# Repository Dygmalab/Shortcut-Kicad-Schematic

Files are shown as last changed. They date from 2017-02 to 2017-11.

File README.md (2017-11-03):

Shortcut v4 schematic and board layout. This is the version that
[Dygma](http://www.dygma.com) used for conducting closed beta testing of the
shortcut gaming keyboard.

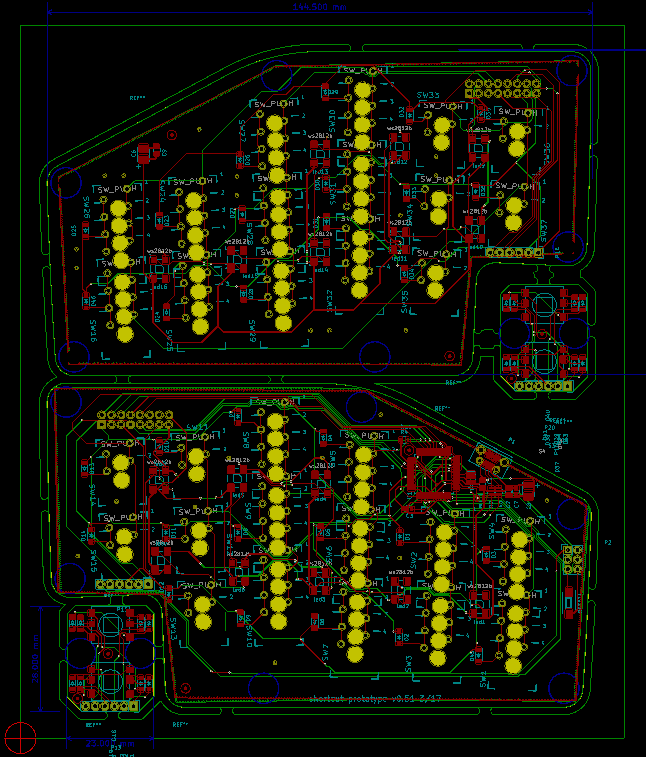
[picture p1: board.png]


[Schematic PDF](schematic.pdf)

Copyright Dygma 2017.

The firmware for the keyboard is part of the [Kaleidoscope
project](https://github.com/keyboardio/Kaleidoscope). The
specific implementation is defined in the [Shortcut Hardware
Plugin](https://github.com/Dygmalab/Kaleidoscope-Hardware-Shortcut).

This documentation describes Open Hardware and is licensed under the
[CERN OHL v. 1.2.](cern_ohl_v_1_2.txt)

You may redistribute and modify this documentation under the terms of the
CERN OHL v.1.2. (http://ohwr.org/cernohl). This documentation is distributed
WITHOUT ANY EXPRESS OR IMPLIED WARRANTY, INCLUDING OF
MERCHANTABILITY, SATISFACTORY QUALITY AND FITNESS FOR A
PARTICULAR PURPOSE. Please see the CERN OHL v.1.2 for applicable
conditions

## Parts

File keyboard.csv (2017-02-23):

Item | Qty | Reference(s) | Value | LibPart | Footprint | Datasheet | farnell #
1 | 2 | C1, C3 | 1u | device:C | Capacitors_SMD:C_0805 |  | 1759422
2 | 3 | C2, C7, C9 | 0.1u | device:C | Capacitors_SMD:C_0805 |  | 1759167
3 | 2 | C6, C8 | 2.2u | device:CP | Capacitors_Tantalum_SMD:TantalC_SizeB_EIA-3528_Reflow |  | 1759424
4 | 46 | D1, D10, D11, D12, D13, D14, D15, D16, D17, D18, D19, D2, D20, D21, D22, D23, D24, D25, D26, D27, D28, D29, D3, D30, D31, D32, D33, D34, D35, D36, D37, D38, D39, D4, D40, D41, D42, D43, D44, D45, D46, D5, D6, D7, D8, D9 | D | device:D | Diodes_SMD:SOD-123 |  | 2454043
5 | 1 | P1 | USB_OTG | conn:USB_OTG |  |  | 2293836
6 | 14 | P10, P11, P12, P13, P14, P17, P20, P3, P4, P5, P6, P7, P8, P9 | CONN_01X01 | conn:CONN_01X01 | Mounting_Holes:MountingHole_4mm
7 | 4 | P15, P16, P18, P19 | CONN_01X06 | conn:CONN_01X06
8 | 1 | P2 | CONN_02X03 | conn:CONN_02X03 | Pin_Headers:Pin_Header_Straight_2x03
9 | 1 | R1 | 10k | device:R | Resistors_SMD:R_0805 |  | 2447553
10 | 2 | R2, R3 | 22r | device:R | Resistors_SMD:R_0805 |  | 9332847
11 | 1 | RESET1 | SW_PUSH | device:SW_PUSH | matt:SW_SPST_FSMSM |  | 9471898
12 | 4 | S1, S2, S3, S4 | alps_4way | alps_4way:alps_4way | fp:alps 4way smt |  | 1435774
13 | 20 | SW1, SW10, SW16, SW2, SW24, SW25, SW26, SW27, SW28, SW29, SW3, SW30, SW31, SW32, SW4, SW5, SW6, SW7, SW8, SW9 | SW_PUSH | device:SW_PUSH | fp:CHERRY_MXx4
14 | 10 | SW11, SW12, SW13, SW14, SW15, SW33, SW34, SW35, SW36, SW37 | SW_PUSH | device:SW_PUSH | fp:CHERRY_MXx2
15 | 1 | U1 | ATmega32U4 | atmel:ATmega32U4 | Housings_QFP:LQFP-44_10x10mm_Pitch0.8mm |  | 1748525
16 | 1 | X1 | CRYSTAL_SMD | device:CRYSTAL_SMD | fp:cstce-v | CSTCE16M0V53 | 2443265
17 | 2 | conn1, conn2 | CONN_02X08 | conn:CONN_02X08 | Socket_Strips:Socket_Strip_Angled_2x08 |  | 1642024
18 | 16 | led1, led10, led11, led12, led13, led14, led15, led16, led2, led3, led4, led5, led6, led7, led8, led9 | ws2812b | ws2812b:ws2812b | WS2812B:WS2812B

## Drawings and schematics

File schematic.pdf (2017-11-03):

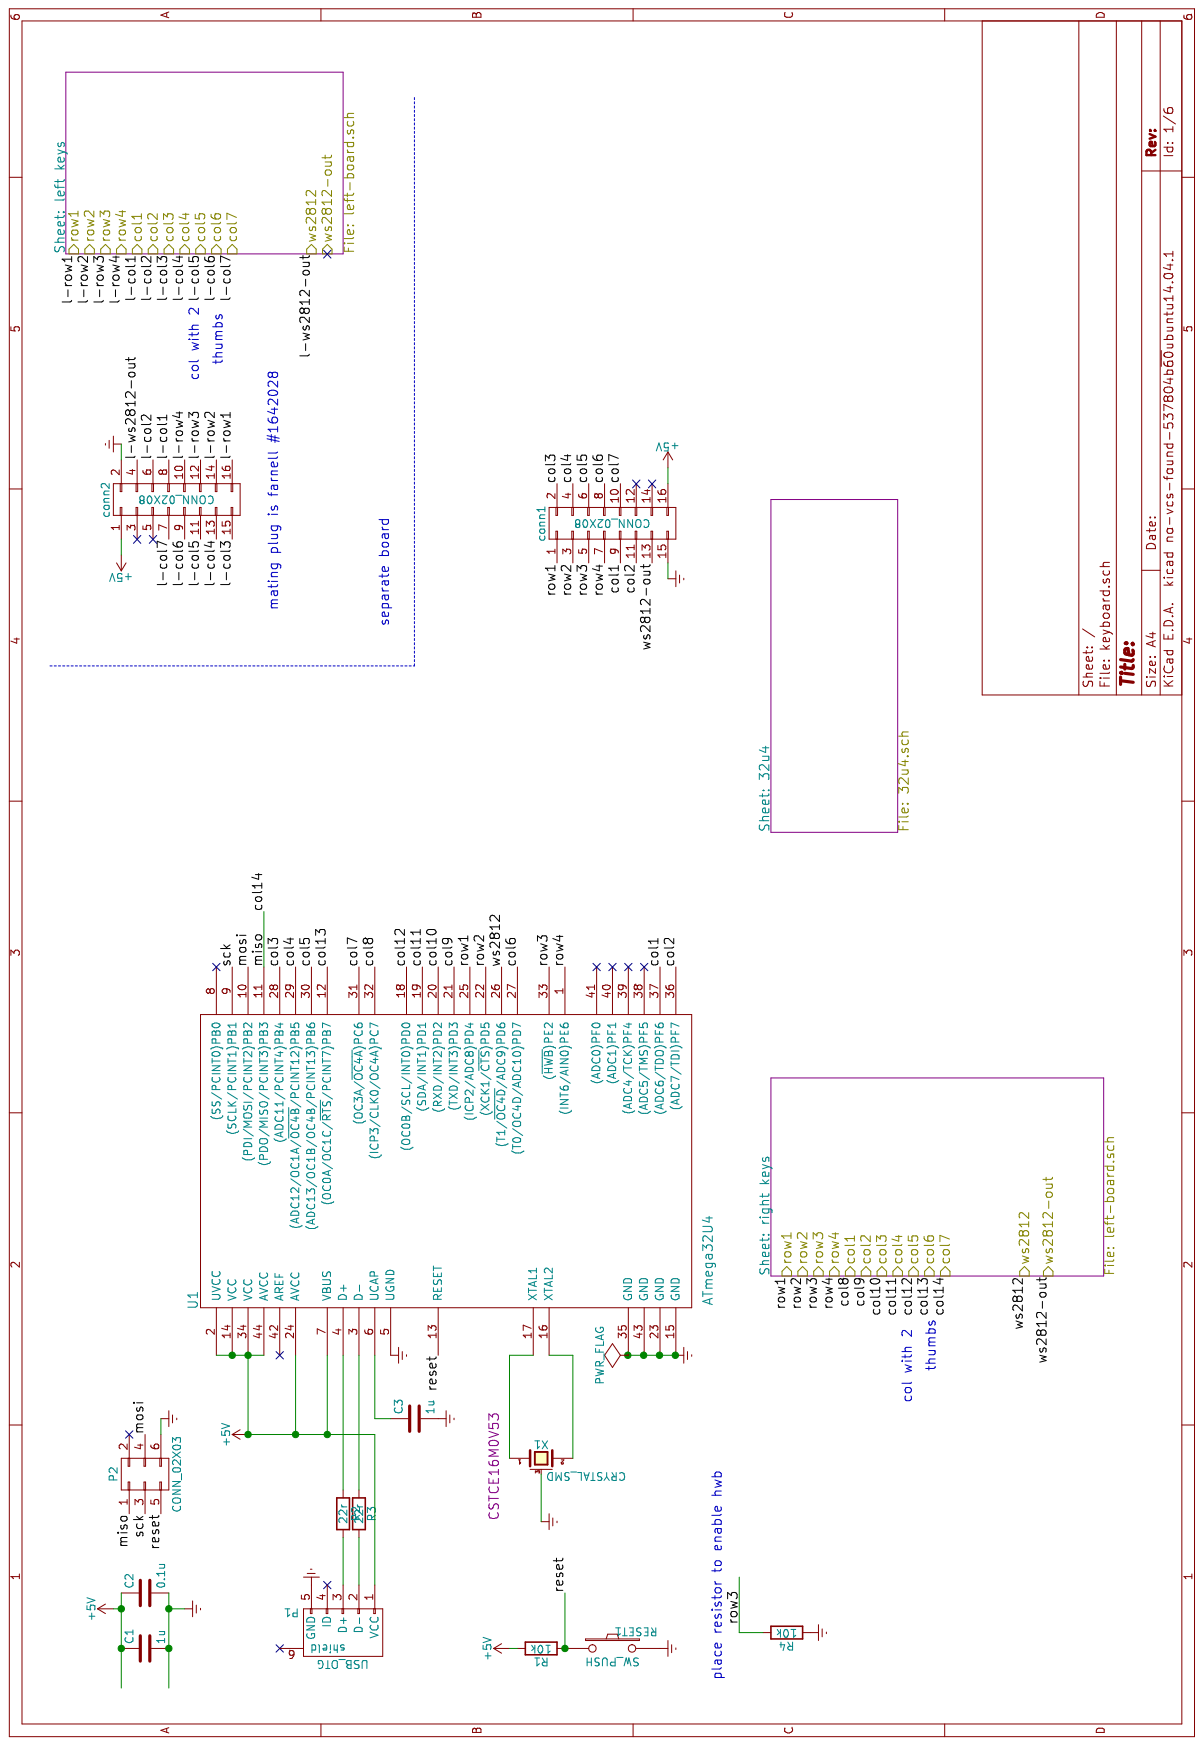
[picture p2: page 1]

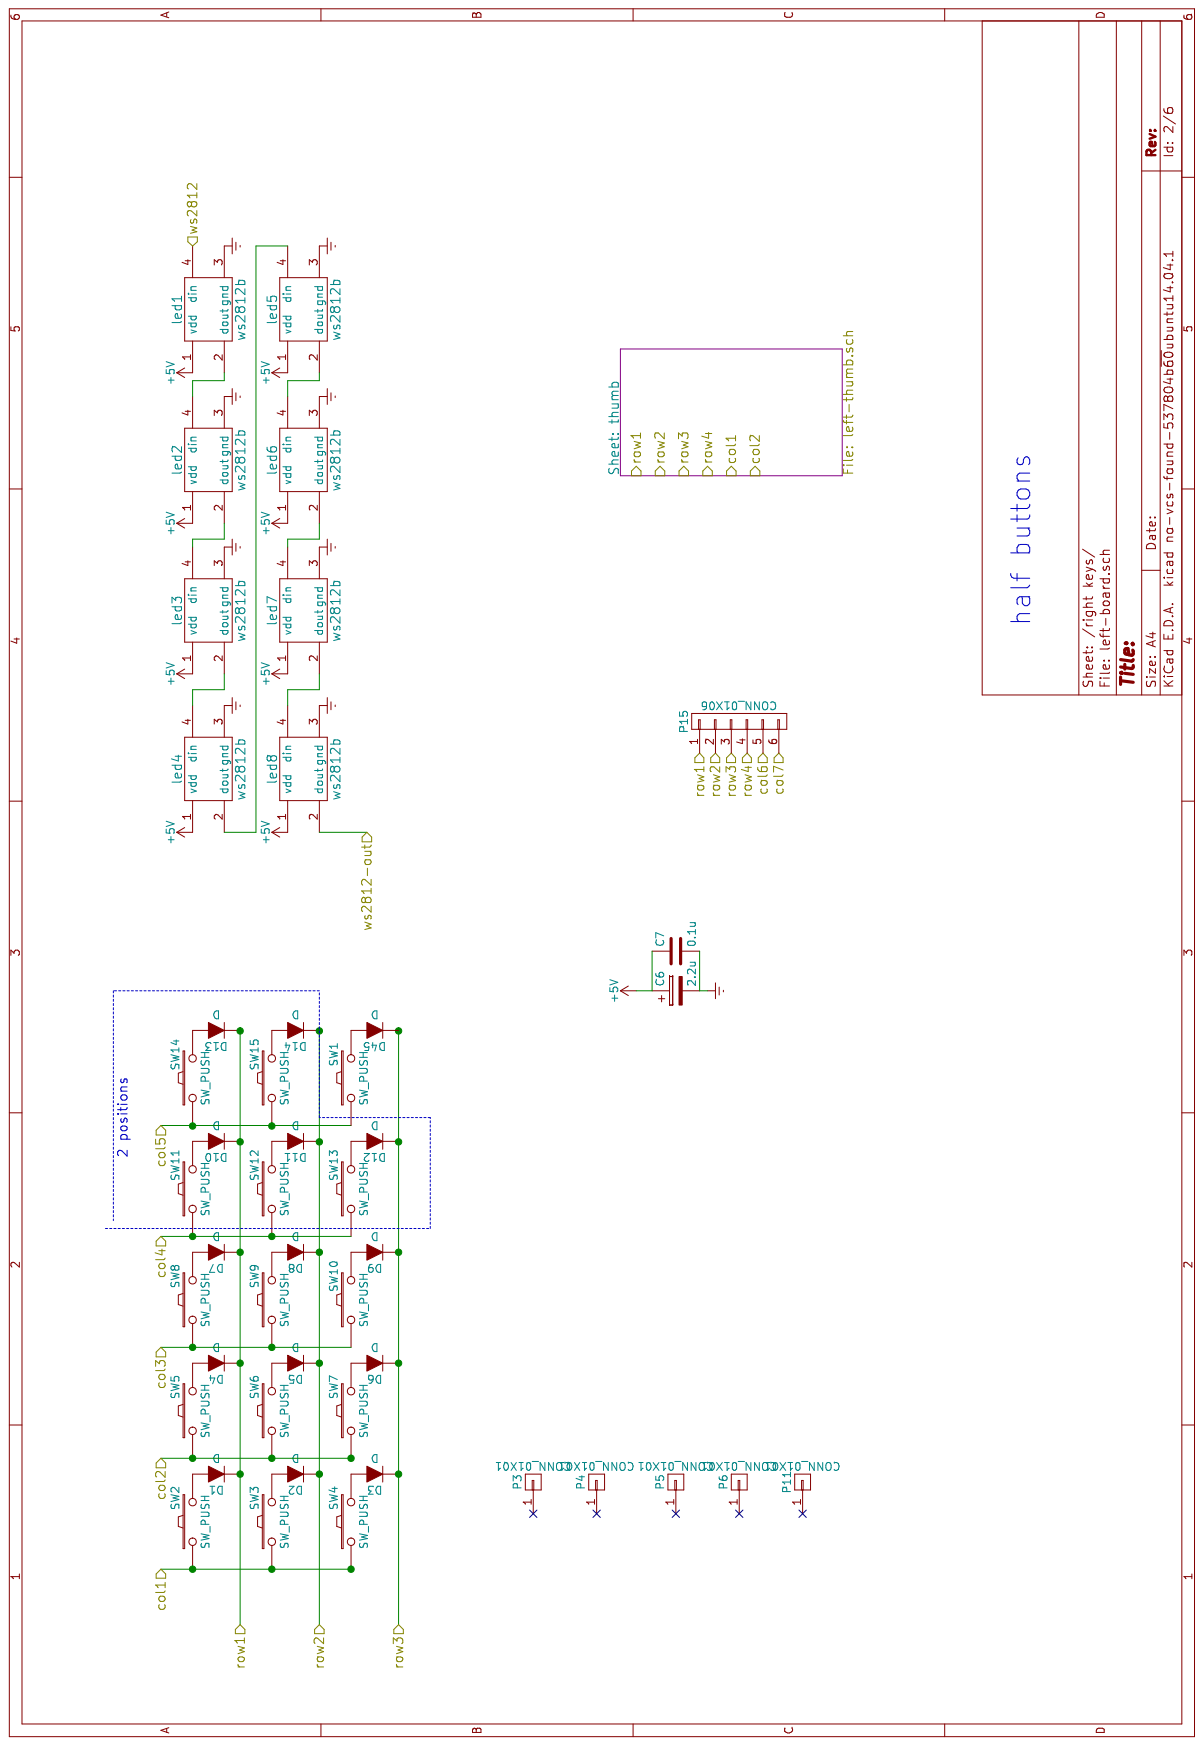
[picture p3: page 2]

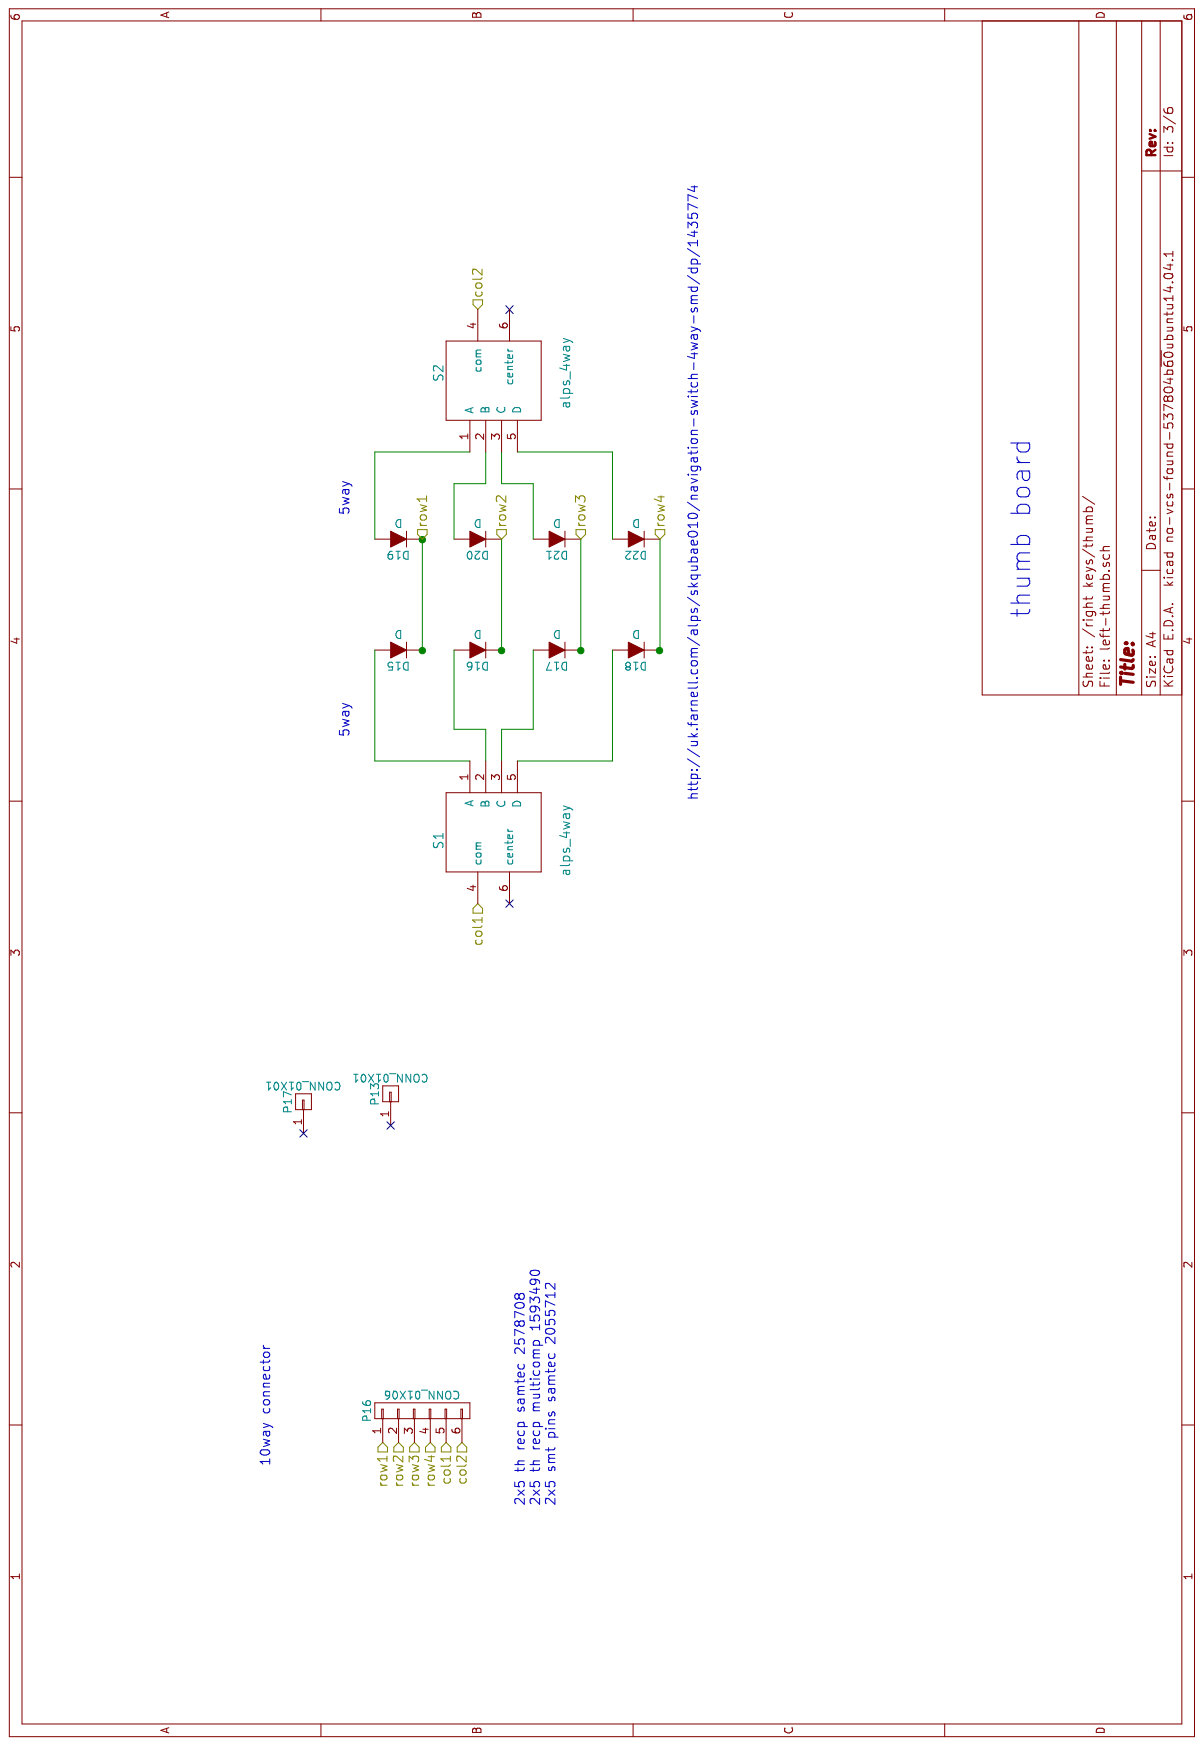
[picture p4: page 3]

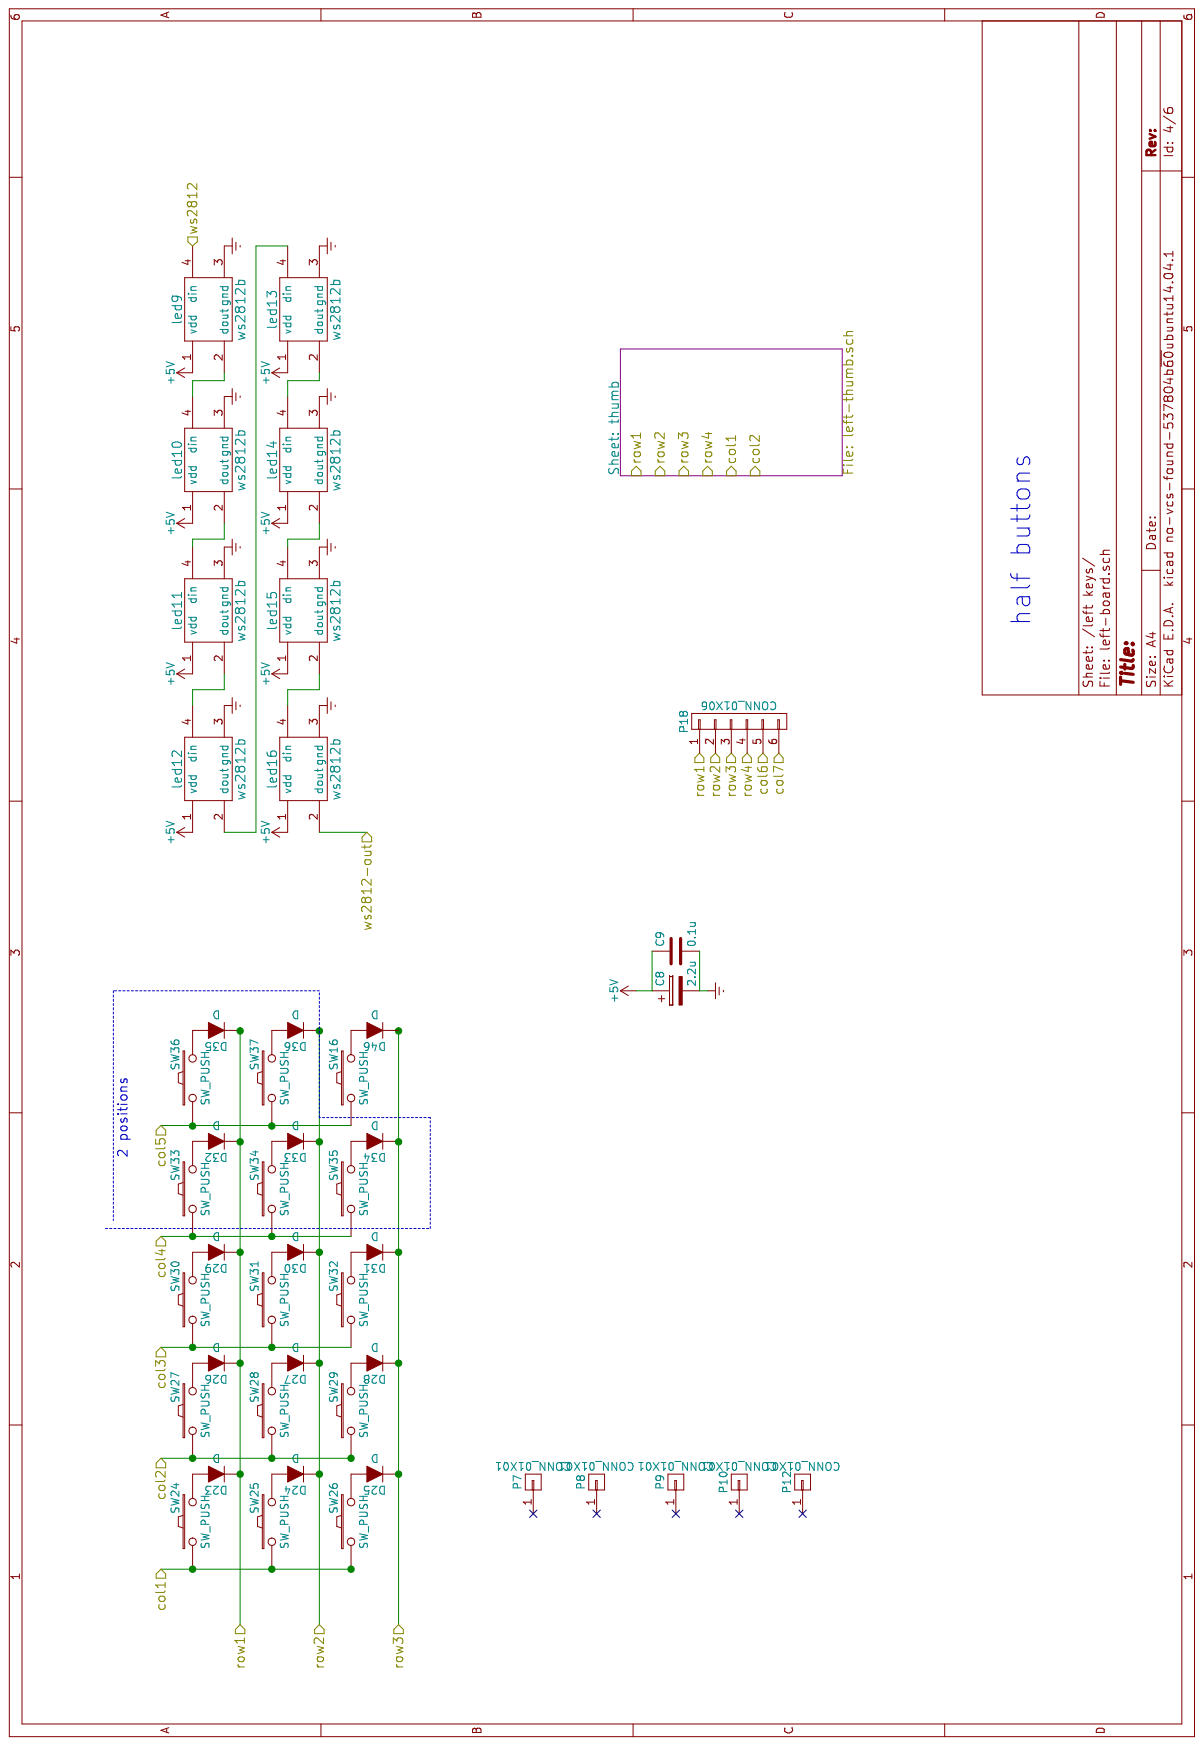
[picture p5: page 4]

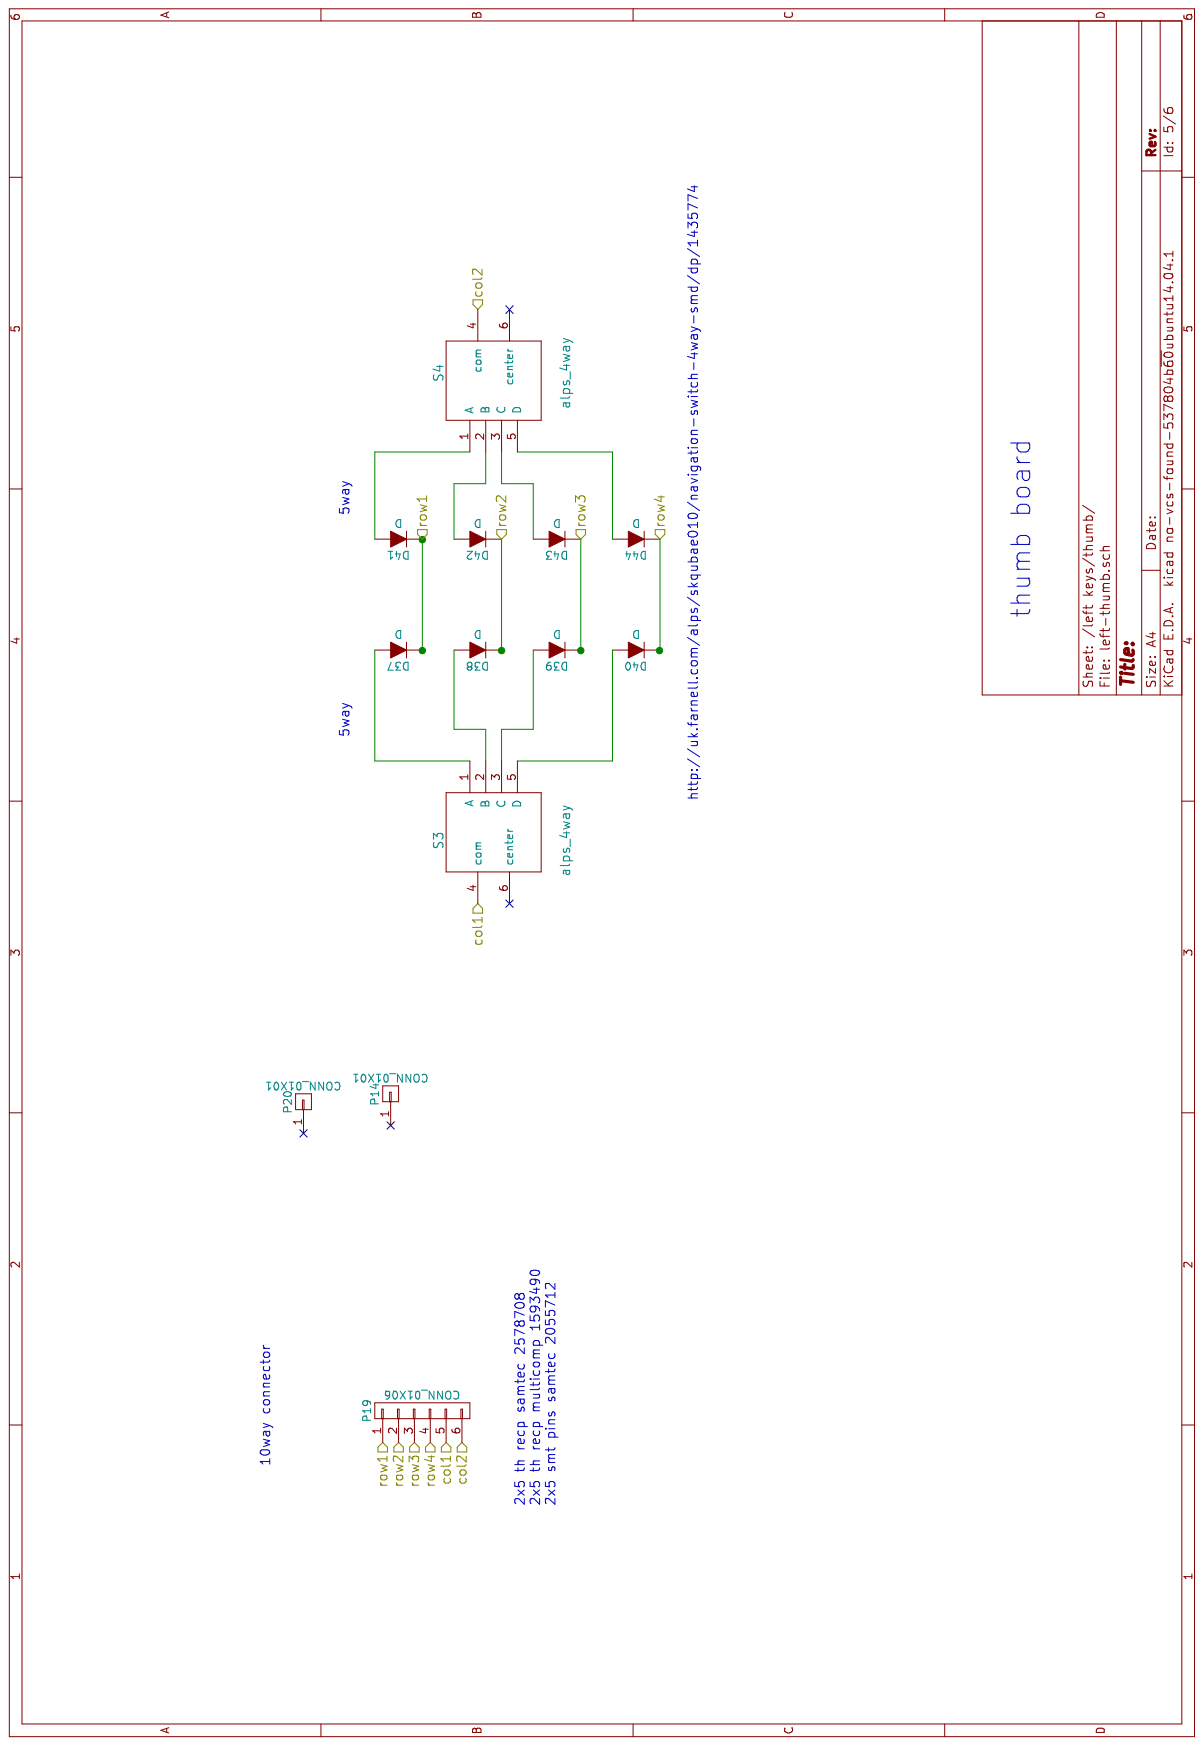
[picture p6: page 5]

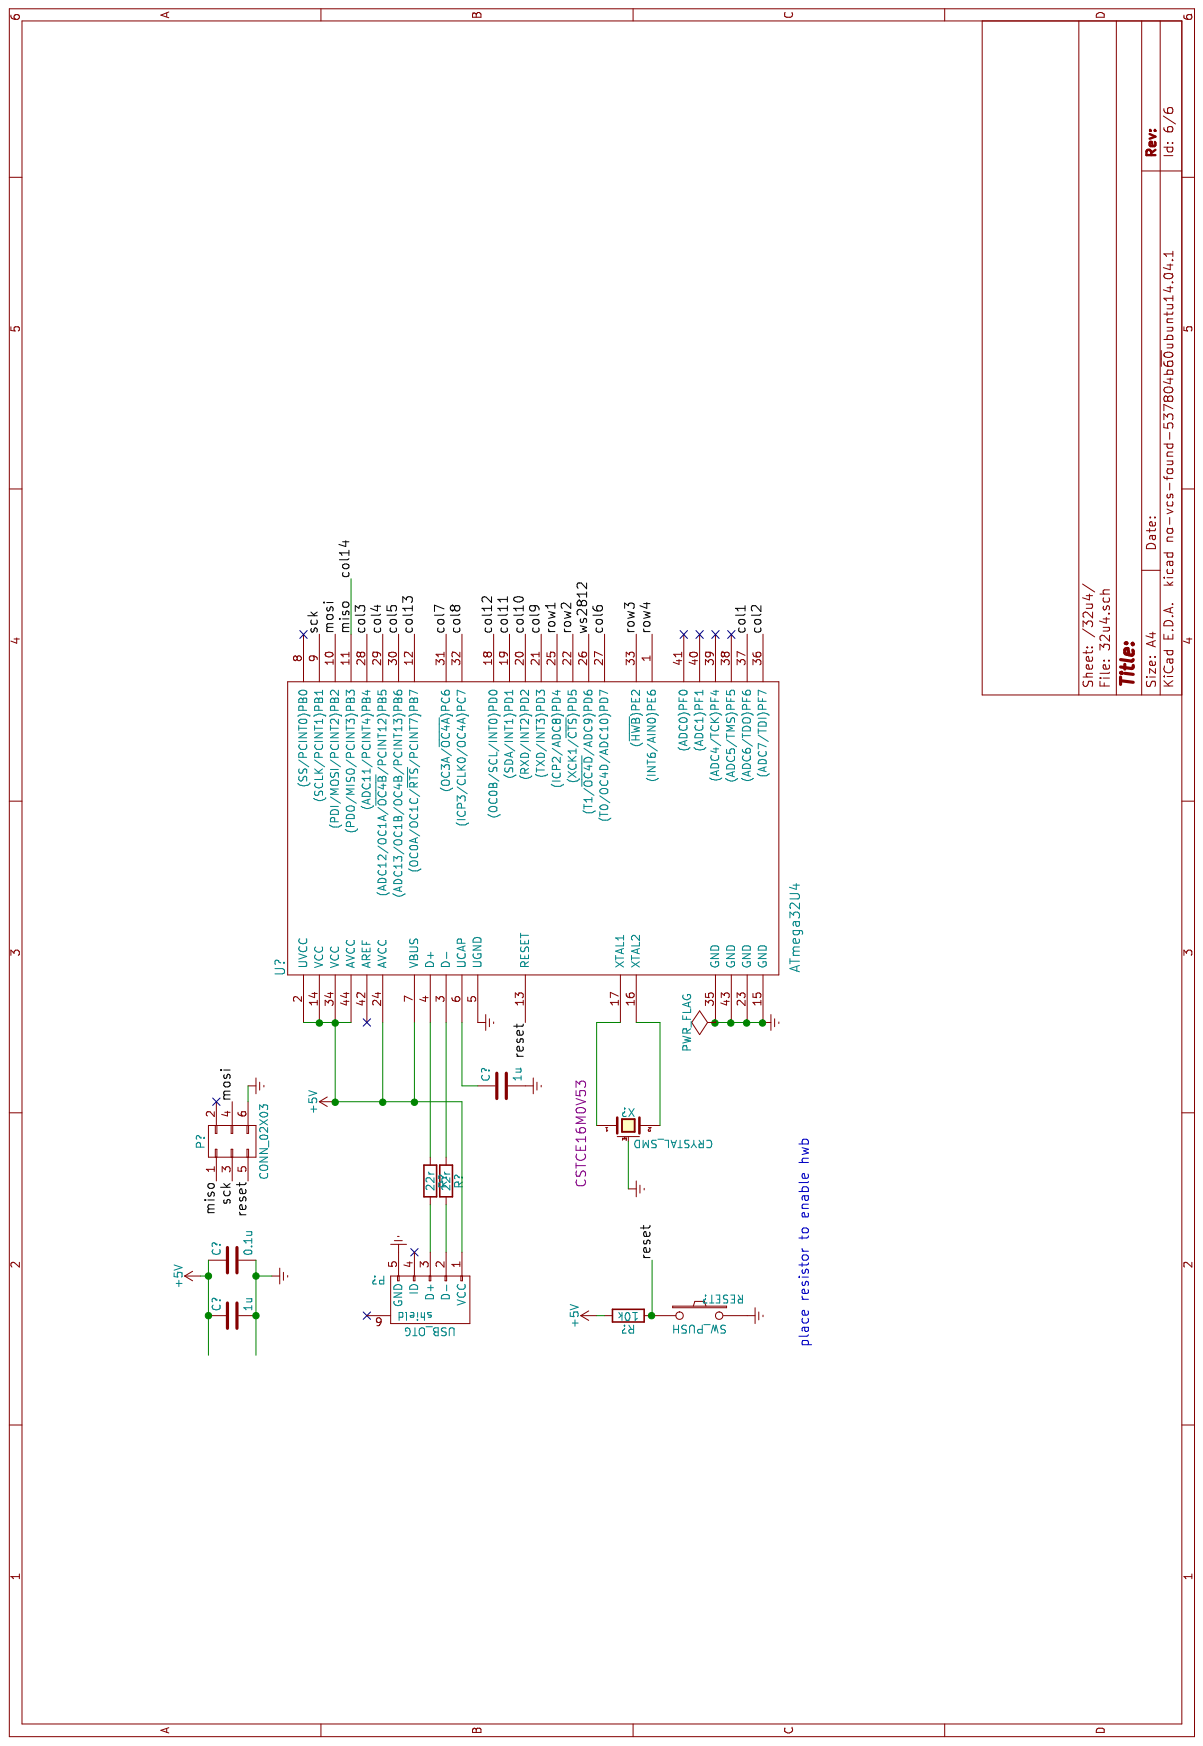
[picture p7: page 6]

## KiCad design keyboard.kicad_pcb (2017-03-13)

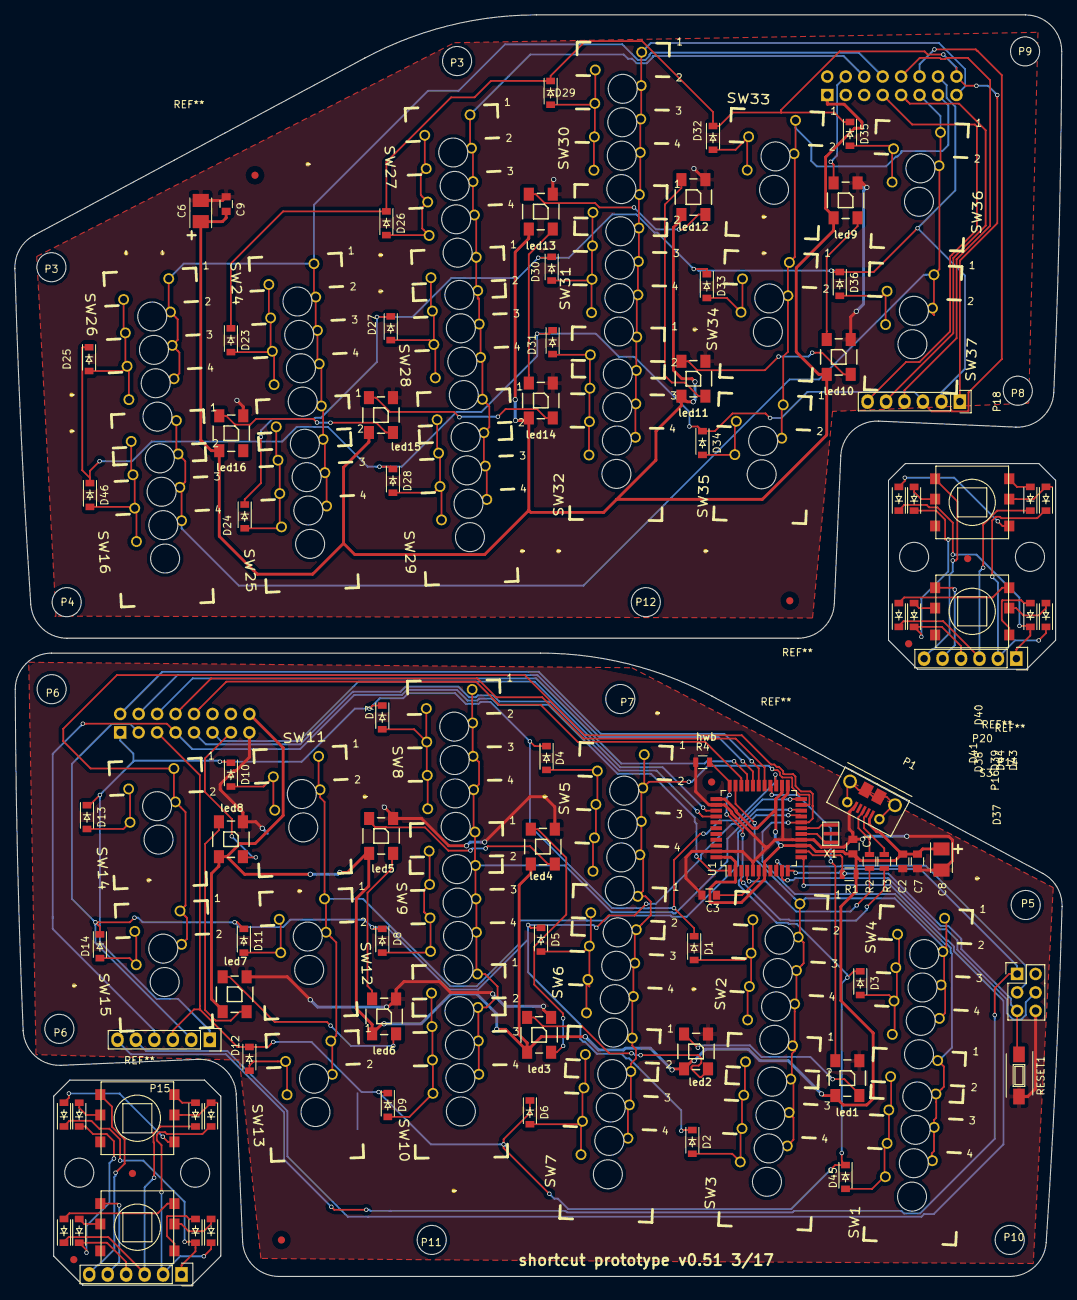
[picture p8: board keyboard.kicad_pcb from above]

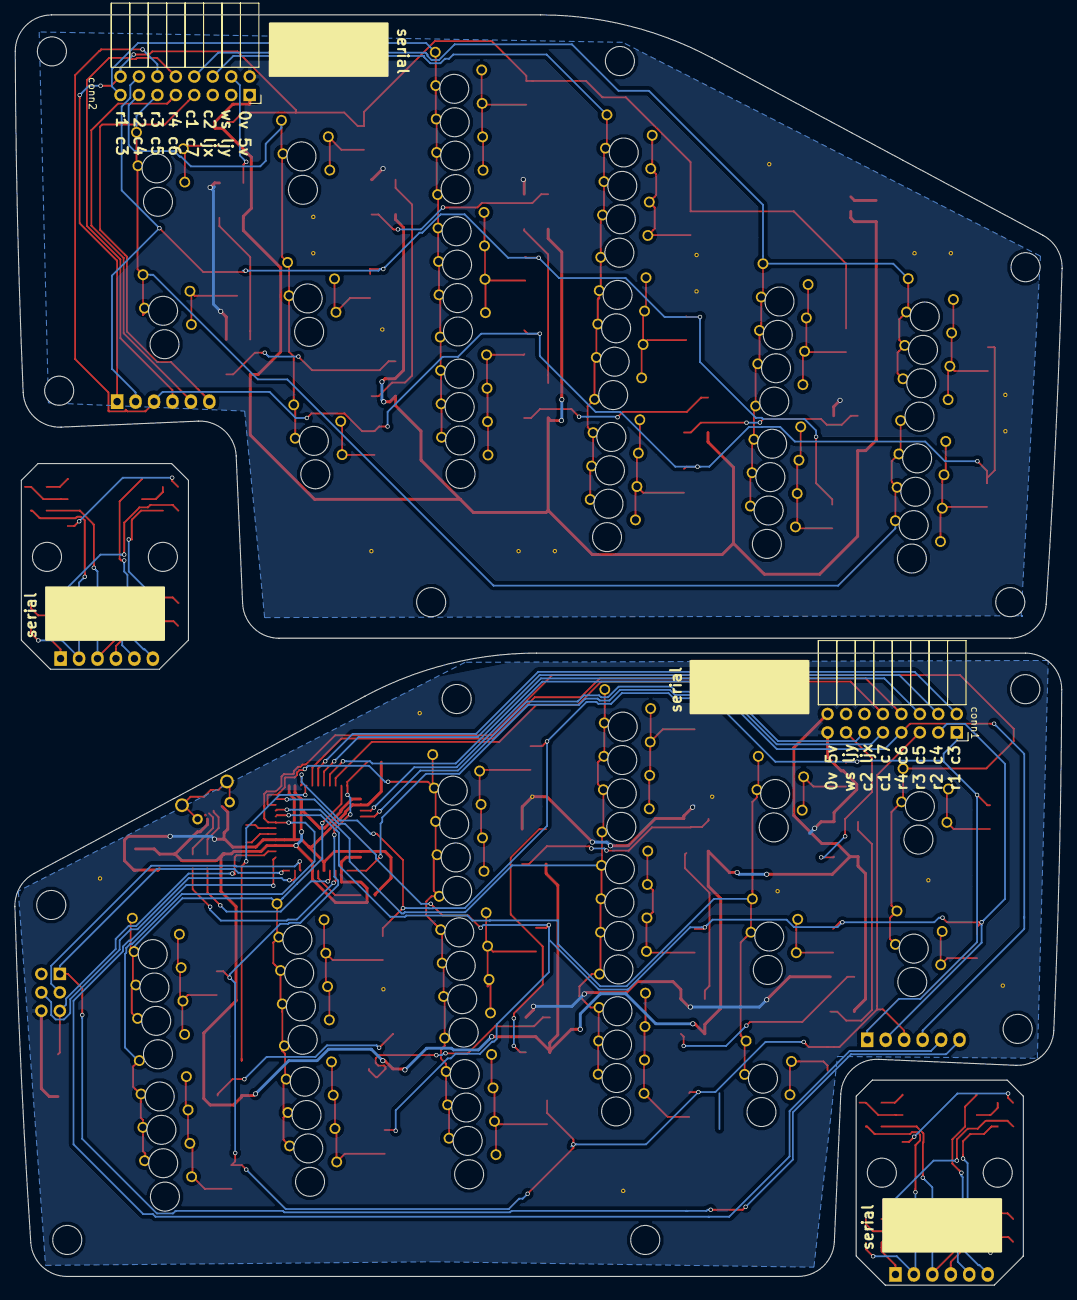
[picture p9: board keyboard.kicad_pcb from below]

Board: 2 copper layers, 144.1 x 174.8 mm, 134 parts (2 on the bottom side), 102 nets.

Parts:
C1, C3: 1u; C_0805
C2, C7, C9: 0.1u; C_0805
C6, C8: 2.2u; TantalC_SizeB_EIA-3528_Reflow
D1, D2, D3, D4, D5, D6, D7, D8, D9, D10, D11, D12, D13, D14, D15, D16, D17, D18, D19, D20, D21, D22, D23, D24, D25, D26, D27, D28, D29, D30, D31, D32, D33, D34, D35, D36, D37, D38, D39, D40, D41, D42, D43, D44, D45, D46: D; SOD-123
P1: USB_OTG; USB MICRO B
P2: CONN_02X03; Pin_Header_Straight_2x03
P3, P3#2, P4, P5, P6, P6#2, P7, P8, P9, P10, P11, P12, P13, P14, P17, P20: CONN_01X01; MountingHole_4mm
P15, P16, P16#2, P18: CONN_01X06; Pin_Header_Straight_1x06
R1, R4: 10k; R_0805
R2, R3: 22r; R_0805
RESET1: SW_PUSH; SW_SPST_FSMSM
S1, S2, S3, S4: alps_4way; alps 4way smt
SW1, SW2, SW3, SW4, SW5, SW6, SW7, SW8, SW9, SW10, SW16, SW24, SW25, SW26, SW27, SW28, SW29, SW30, SW31, SW32: SW_PUSH; CHERRY_MXx4
SW11, SW12, SW13, SW14, SW15, SW33, SW34, SW35, SW36, SW37: SW_PUSH; CHERRY_MXx2
U1: ATmega32U4; LQFP-44_10x10mm_Pitch0.8mm
X1: CRYSTAL_SMD; cstce-v
conn1, conn2: CONN_02X08; Socket_Strip_Angled_2x08
led1, led2, led3, led4, led5, led6, led7, led8, led9, led10, led11, led12, led13, led14, led15, led16: ws2812b; WS2812B

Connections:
+5V: C1.1, C2.1, C6.1, C7.1, C8.1, C9.1, P1.1, R1.2, U1.2, U1.7, U1.14, U1.24, U1.34, U1.44, conn1.16, conn2.1, led1.1, led2.1, led3.1, led4.1, led5.1, led6.1, led7.1, led8.1, led9.1, led10.1, led11.1, led12.1, led13.1, led14.1, led15.1, led16.1
/col1: U1.37, conn1.9
/col2: U1.36, conn1.11
/col3: U1.28, conn1.2
/col4: U1.29, conn1.4
/col5: U1.30, conn1.6
/col6: U1.27, conn1.8
/col7: U1.31, conn1.10
/col8: SW2.1, SW3.1, SW4.1, U1.32
/col9: SW5.1, SW6.1, SW7.1, U1.21
/col10: SW8.1, SW9.1, SW10.1, U1.20
/col11: SW11.1, SW12.1, SW13.1, U1.19
/col12: SW1.1, SW14.1, SW15.1, U1.18
/col13: P15.5, U1.12
/col14: P2.1, P15.6, U1.11
/l-col1: SW24.1, SW25.1, SW26.1, conn2.8
/l-col2: SW27.1, SW28.1, SW29.1, conn2.6
/l-col3: SW30.1, SW31.1, SW32.1, conn2.15
/l-col4: SW33.1, SW34.1, SW35.1, conn2.13
/l-col5: SW16.1, SW36.1, SW37.1, conn2.11
/l-col6: P18.5, conn2.9
/l-col7: P18.6, conn2.7
/l-row1: D23.1, D26.1, D29.1, D32.1, D35.1, P18.1, conn2.16
/l-row2: D24.1, D27.1, D30.1, D33.1, D36.1, P18.2, conn2.14
/l-row3: D25.1, D28.1, D31.1, D34.1, D46.1, P18.3, conn2.12
/l-row4: P18.4, conn2.10
/l-ws2812-out: conn2.4, led9.4
/mosi: P2.4, U1.10
/reset: P2.5, R1.1, RESET1.1, U1.13
/right keys/thumb/col1: P16.5, P16#2.5, S1.4, S3.4
/right keys/thumb/col2: P16.6, P16#2.6, S2.4, S4.4
/right keys/thumb/row1: D15.1, D19.1, D37.1, D41.1, P16.1, P16#2.1
/right keys/thumb/row2: D16.1, D20.1, D38.1, D42.1, P16.2, P16#2.2
/right keys/thumb/row3: D17.1, D21.1, D39.1, D43.1, P16.3, P16#2.3
/right keys/thumb/row4: D18.1, D22.1, D40.1, D44.1, P16.4, P16#2.4
/row1: D1.1, D4.1, D7.1, D10.1, D13.1, P15.1, U1.25, conn1.1
/row2: D2.1, D5.1, D8.1, D11.1, D14.1, P15.2, U1.22, conn1.3
/row3: D3.1, D6.1, D9.1, D12.1, D45.1, P15.3, R4.2, U1.33, conn1.5
/row4: P15.4, U1.1, conn1.7
/sck: P2.3, U1.9
/ws2812: U1.26, led1.4
/ws2812-out: conn1.13, led8.2
Earth: C1.2, C2.2, C3.2, C6.2, C7.2, C8.2, C9.2, P1.5, P2.6, R4.1, RESET1.2, U1.5, U1.15, U1.23, U1.35, U1.43, X1.3, conn1.15, conn2.2, led1.3, led2.3, led3.3, led4.3, led5.3, led6.3, led7.3, led8.3, led9.3, led10.3, led11.3, led12.3, led13.3, led14.3, led15.3, led16.3
unnamed: C3.1, U1.6
unnamed: D1.2, SW2.2
unnamed: D2.2, SW3.2
unnamed: D3.2, SW4.2
unnamed: D4.2, SW5.2
unnamed: D5.2, SW6.2
unnamed: D6.2, SW7.2
unnamed: D7.2, SW8.2
unnamed: D8.2, SW9.2
unnamed: D9.2, SW10.2
unnamed: D10.2, SW11.2
unnamed: D11.2, SW12.2
unnamed: D12.2, SW13.2
unnamed: D13.2, SW14.2
unnamed: D14.2, SW15.2
unnamed: D15.2, D37.2, S1.1, S3.1
unnamed: D16.2, D38.2, S1.2, S3.2
unnamed: D17.2, D39.2, S1.3, S3.3
unnamed: D18.2, D40.2, S1.5, S3.5
unnamed: D19.2, D41.2, S2.1, S4.1
unnamed: D20.2, D42.2, S2.2, S4.2
unnamed: D21.2, D43.2, S2.3, S4.3
unnamed: D22.2, D44.2, S2.5, S4.5
unnamed: D23.2, SW24.2
unnamed: D24.2, SW25.2
unnamed: D25.2, SW26.2
unnamed: D26.2, SW27.2
unnamed: D27.2, SW28.2
unnamed: D28.2, SW29.2
unnamed: D29.2, SW30.2
unnamed: D30.2, SW31.2
unnamed: D31.2, SW32.2
unnamed: D32.2, SW33.2
unnamed: D33.2, SW34.2
unnamed: D34.2, SW35.2
unnamed: D35.2, SW36.2
unnamed: D36.2, SW37.2
unnamed: D45.2, SW1.2
unnamed: D46.2, SW16.2
unnamed: P1.2, R3.2
unnamed: P1.3, R2.2
unnamed: R2.1, U1.4
unnamed: R3.1, U1.3
unnamed: U1.16, X1.2
unnamed: U1.17, X1.1
unnamed: led1.2, led2.4
unnamed: led2.2, led3.4
unnamed: led3.2, led4.4
unnamed: led4.2, led5.4
unnamed: led5.2, led6.4
unnamed: led6.2, led7.4
unnamed: led7.2, led8.4
unnamed: led10.2, led11.4
unnamed: led9.2, led10.4
unnamed: led11.2, led12.4
unnamed: led12.2, led13.4
unnamed: led13.2, led14.4
unnamed: led14.2, led15.4
unnamed: led15.2, led16.4

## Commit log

2016-12-06 mid sheet organise
    [keyboard.sch, left-board.sch, left-thumb.sch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]
2016-12-06 finished schematic
    [keyboard.sch, left-board.sch, left-thumb.sch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]
2016-12-07 added wire interconnects between sockets
    [keyboard.sch, left-board.sch, left-thumb.sch]
2016-12-07 right hand side initial layout
    [keyboard.kicad_pcb]
2016-12-07 picoflex connectors & good idea of board layout
    [keyboard.kicad_pcb, keyboard.sch, left-board.sch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]
2016-12-12 libs and thumboard components done
    [keyboard.kicad_pcb, keyboard.sch, left-board.sch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]
2016-12-13 smt 4 ways
    [keyboard.kicad_pcb, left-board.sch, left-thumb.sch]
2016-12-15 removed joysticks, changed board conns, changed thumb conns
    [keyboard.kicad_pcb, keyboard.sch, left-board.sch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]
2016-12-15 buttons shifted
    [keyboard.kicad_pcb]
2016-12-15 nearly routed
    [keyboard.kicad_pcb, keyboard.sch, left-board.sch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]
2016-12-16 final checks, silks, labels, ground pours, layout
    [keyboard.kicad_pcb, keyboard.sch, left-board.sch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]
2016-12-16 sent to fab
    [keyboard.kicad_pcb]
2017-01-13 part numbers for 4 ways and reset switch
    [keyboard.sch, left-board.sch, left-thumb.sch]
2017-02-21 v5 switches routed + outline
    [keyboard.kicad_pcb, keyboard.sch, left-board.sch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]
2017-02-22 v5 prefab
    [keyboard.kicad_pcb]
2017-02-24 fix non smt components
    [keyboard.kicad_pcb]
2017-02-28 fixed: silks, fids, col2 via, serial patches
    [keyboard.kicad_pcb]
2017-02-28 removed silk cross
    [keyboard.kicad_pcb]
2017-02-28 added hwb resistor
    [keyboard.kicad_pcb, keyboard.sch, left-board.sch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]
2017-02-28 redid thumboard components
    [keyboard.kicad_pcb]
2017-03-02 shortened thumbs, fid refs
    [keyboard.kicad_pcb]
2017-03-02 fix vias under pads, serial silks
    [keyboard.kicad_pcb]
2017-03-07 changed size to a3 and moved boards
    [keyboard.kicad_pcb]
2017-03-13 moved outlines
    [keyboard.kicad_pcb]
2017-11-03 libraries and footprints
2017-11-03 schematic and board layout
